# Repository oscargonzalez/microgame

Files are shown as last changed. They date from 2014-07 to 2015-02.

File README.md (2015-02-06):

MicroGame - Custom Arduino Compatible Gamming Platform
======================================================

MicroGame

The MicroGame is an experiment of making a custom portable platform for gamming compatible with Arduino. It's based on a small monochrome 128x64 pixels OLED from Adafruit and a ATmega32U40 8-bits microcontroller running at 8MHz.
All hardware design and game source code is writed from scratch and you can find all the file sin this repository if you want to build your own. You can modify, share and make improvements as you like but do not forget to shoot me and email and show me your work!

First blog post:
http://blog.bricogeek.com/noticias/electronica/microgame-consola-de-juego-casera-basada-en-arduino/

Final proyect post:
http://blog.bricogeek.com/noticias/arduino/microgame-consola-de-juego-compatible-con-arduino-proyecto-final/

Oscar Gonzalez August 2014 - January 2015
www.bricogeek.com

Repository Contents
-------------------
* **/USB driver** - USB driver (tested on Win 7 64-bits). Identifies as Sparkfun Pro Micro 3.3V @ 8MHz
* **/datasheet** - Various datasheets for reference
* **/eagle files** - Eagle design files of the board (schematic and PCB)
* **/src** - Source files for the game for at least Arduino IDE 1.0

License Information
-------------------
The hardware is released under [Creative Commons Share-alike 3.0](http://creativecommons.org/licenses/by-sa/3.0/).  
All other code is open source so please feel free to do anything you want with it; you buy me a beer if you use this and we meet someday ([Beerware license](http://en.wikipedia.org/wiki/Beerware)).

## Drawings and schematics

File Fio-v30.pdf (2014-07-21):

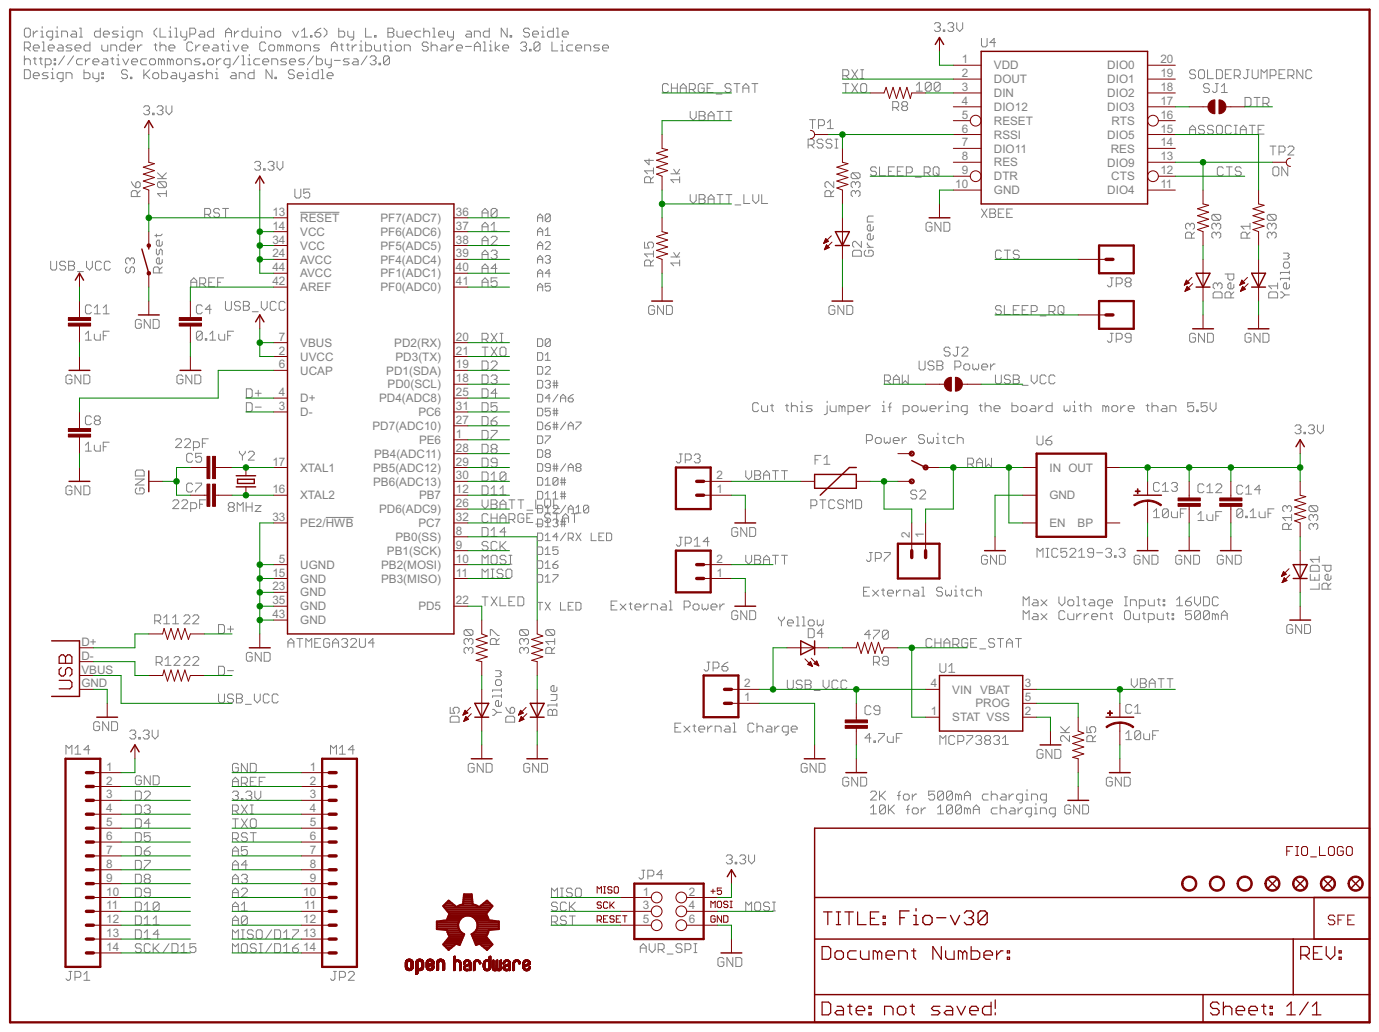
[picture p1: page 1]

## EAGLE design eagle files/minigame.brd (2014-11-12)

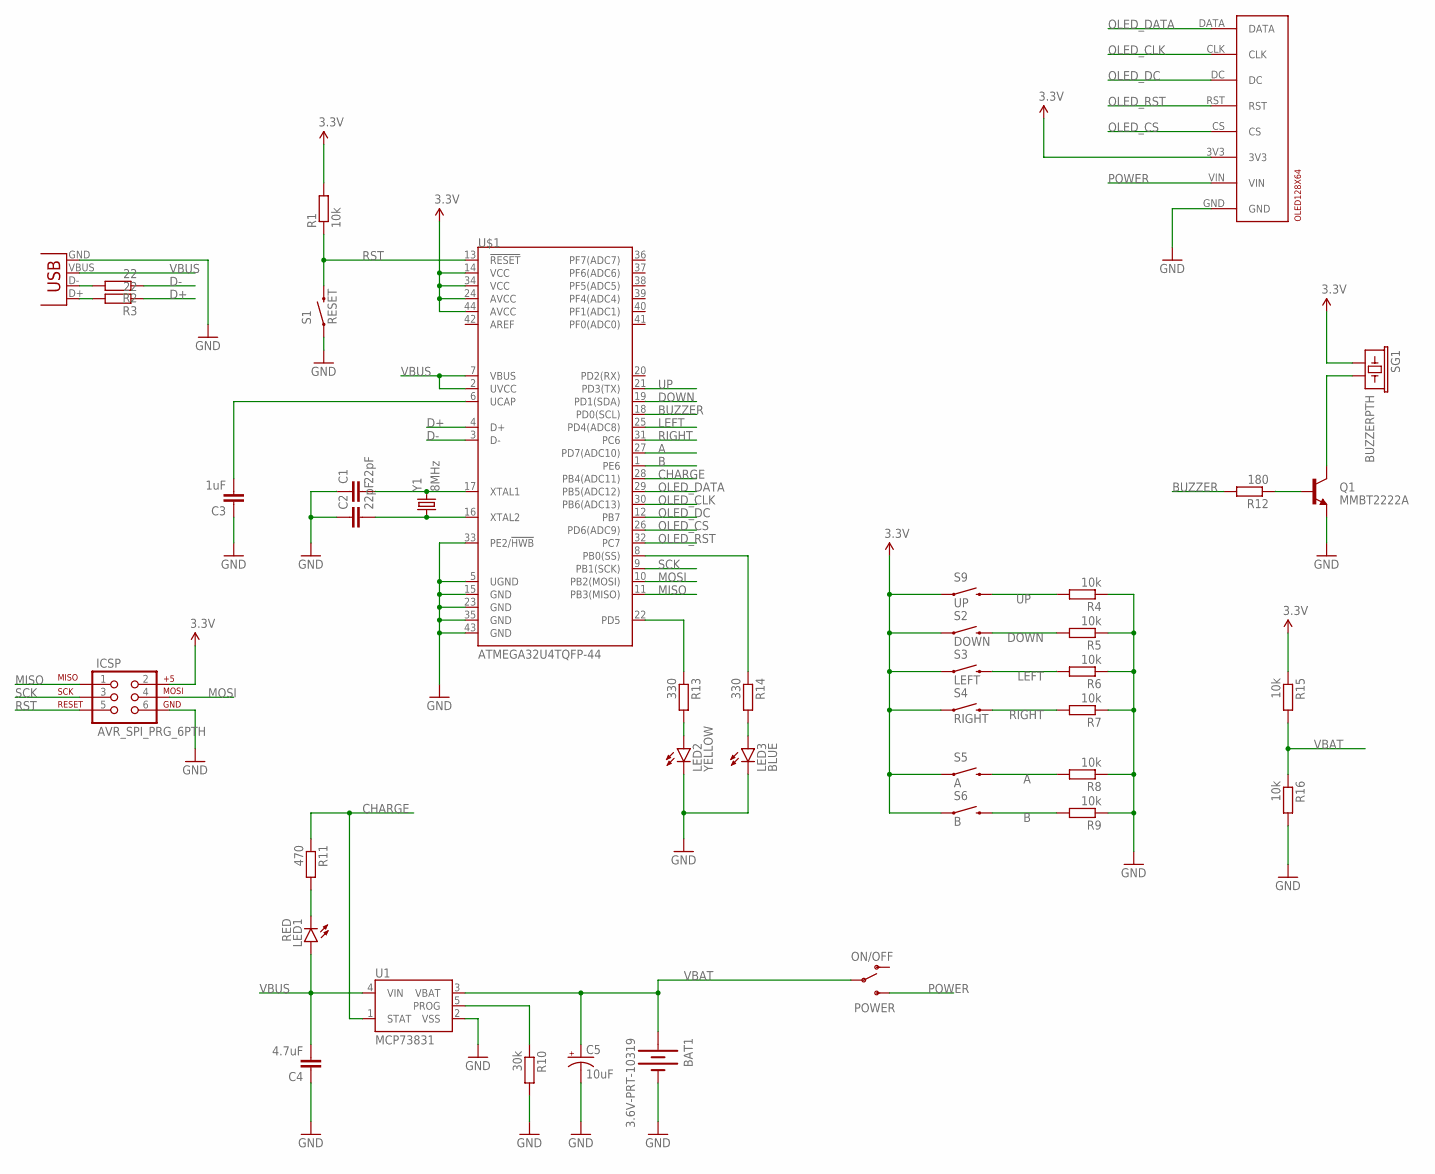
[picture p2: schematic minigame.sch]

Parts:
BAT1: 3.6V-PRT-10319; BATTCON_245MM_PTH
C1, C2: 22pF; 1206
C3: 1uF; 1206
C4: 4.7uF; 1206
C5: 10uF; PANASONIC_D
ICSP: AVR_SPI_PRG_6PTH; 2X3
JP1: USB-SMD-NS; USB-MINIB-NOSTOP
LED1: RED; LED-0603
LED2: YELLOW; LED-0603
LED3: BLUE; LED-0603
OLED128X64: OLED128X64-ADAFRUIT938; 938
POWER: ON/OFF; AYZ0202
Q1: MMBT2222A; SOT23-3
R1, R4, R5, R6, R7, R8, R9, R15, R16: 10k; M0805
R2, R3: 22; M0805
R10: 30k; M0805
R11: 470; M0805
R12: 180; M0805
R13, R14: 330; M0805
S1: RESET; TACTILE-SWITCH-SMD
S2: DOWN; TACTILE_SWITCH_TALL
S3: LEFT; TACTILE_SWITCH_TALL
S4: RIGHT; TACTILE_SWITCH_TALL
S5: A; TACTILE_SWITCH_TALL
S6: B; TACTILE_SWITCH_TALL
S9: UP; TACTILE_SWITCH_TALL
SG1: BUZZERPTH; BUZZER-12MM
U1: MCP73831; SOT23-5
U$1: ATMEGA32U4TQFP-44; TQFP44
Y1: 8MHz; HC49US

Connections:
3.3V: ICSP.2, OLED128X64.3V3, R1.2, R15.1, S2.A2 (1), S3.A2 (1), S4.A2 (1), S5.A2 (1), S6.A2 (1), S9.A2 (1), SG1.+ (1), U$1.14 (VCC), U$1.24 (AVCC), U$1.34 (VCC), U$1.44 (AVCC)
A: R8.2, S5.B2 (2), U$1.27 (PD7(ADC10))
B: R9.2, S6.B2 (2), U$1.1 (PE6)
BUZZER: R12.2, U$1.18 (PD0(SCL))
CHARGE: R11.1, U1.1 (STAT), U$1.28 (PB4(ADC11))
D+: R3.1, U$1.4 (D+)
D-: R2.1, U$1.3 (D-)
DOWN: R5.2, S2.B2 (2), U$1.19 (PD1(SDA))
GND: BAT1.2 (-), C1.1, C2.1, C3.1, C4.1, C5.-, ICSP.6, JP1.GND, LED2.C, LED3.C, OLED128X64.GND, Q1.2 (E), R4.1, R5.1, R6.1, R7.1, R8.1, R9.1, R10.2, R16.2, S1.1, U1.2 (VSS), U$1.5 (UGND), U$1.15 (GND), U$1.23 (GND), U$1.33 (PE2/!HWB), U$1.35 (GND), U$1.43 (GND)
LEFT: R6.2, S3.B2 (2), U$1.25 (PD4(ADC8))
MISO: ICSP.1, U$1.11 (PB3(MISO))
MOSI: ICSP.4, U$1.10 (PB2(MOSI))
unnamed: C1.2, U$1.17 (XTAL1), Y1.2
unnamed: C2.2, U$1.16 (XTAL2), Y1.1
unnamed: Q1.3 (C), SG1.- (2)
unnamed: JP1.D-, R2.2
unnamed: JP1.D+, R3.2
unnamed: C3.2, U$1.6 (UCAP)
unnamed: R10.1, U1.5 (PROG)
unnamed: LED1.C, R11.2
unnamed: Q1.1 (B), R12.1
unnamed: LED2.A, R13.2
unnamed: LED3.A, R14.2
unnamed: R13.1, U$1.22 (PD5)
unnamed: R14.1, U$1.8 (PB0(SS))
OLED_CLK: OLED128X64.CLK, U$1.30 (PB6(ADC13))
OLED_CS: OLED128X64.CS, U$1.26 (PD6(ADC9))
OLED_DATA: OLED128X64.DATA, U$1.29 (PB5(ADC12))
OLED_DC: OLED128X64.DC, U$1.12 (PB7)
OLED_RST: OLED128X64.RST, U$1.32 (PC7)
POWER: OLED128X64.VIN, POWER.3 (S)
RIGHT: R7.2, S4.B2 (2), U$1.31 (PC6)
RST: ICSP.5, R1.1, S1.3 (2), U$1.13 (!RESET)
SCK: ICSP.3, U$1.9 (PB1(SCK))
UP: R4.2, S9.B2 (2), U$1.21 (PD3(TX))
VBAT: BAT1.3 (+), C5.+, POWER.2, R15.2, R16.1, U1.3 (VBAT)
VBUS: C4.2, JP1.VBUS, LED1.A, U1.4 (VIN), U$1.2 (UVCC), U$1.7 (VBUS)

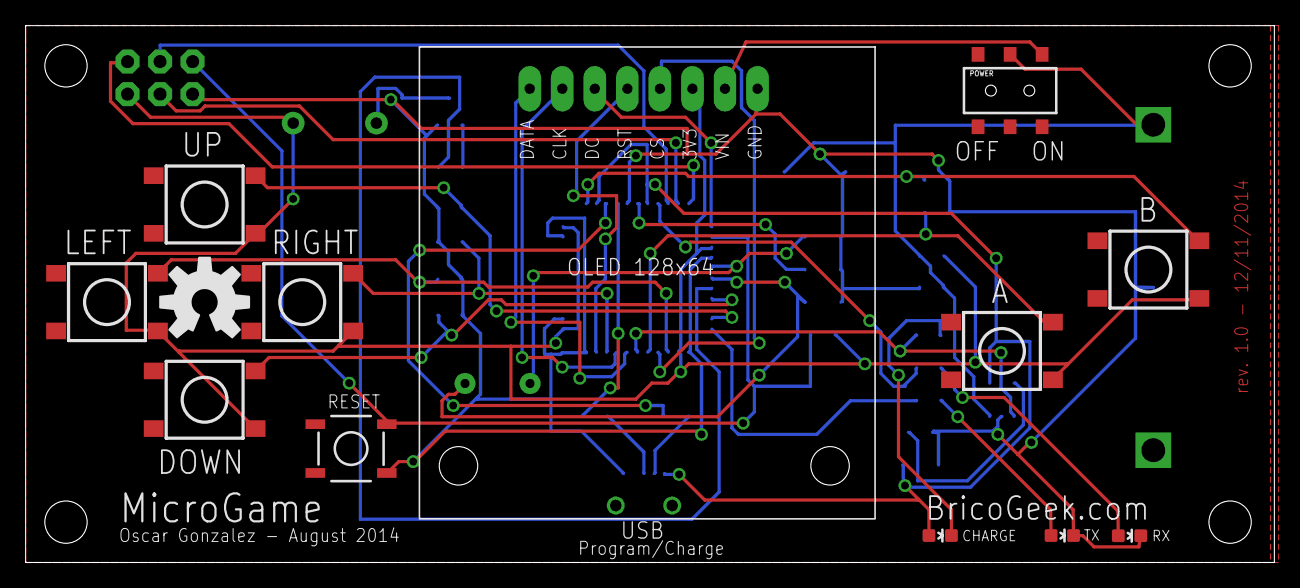
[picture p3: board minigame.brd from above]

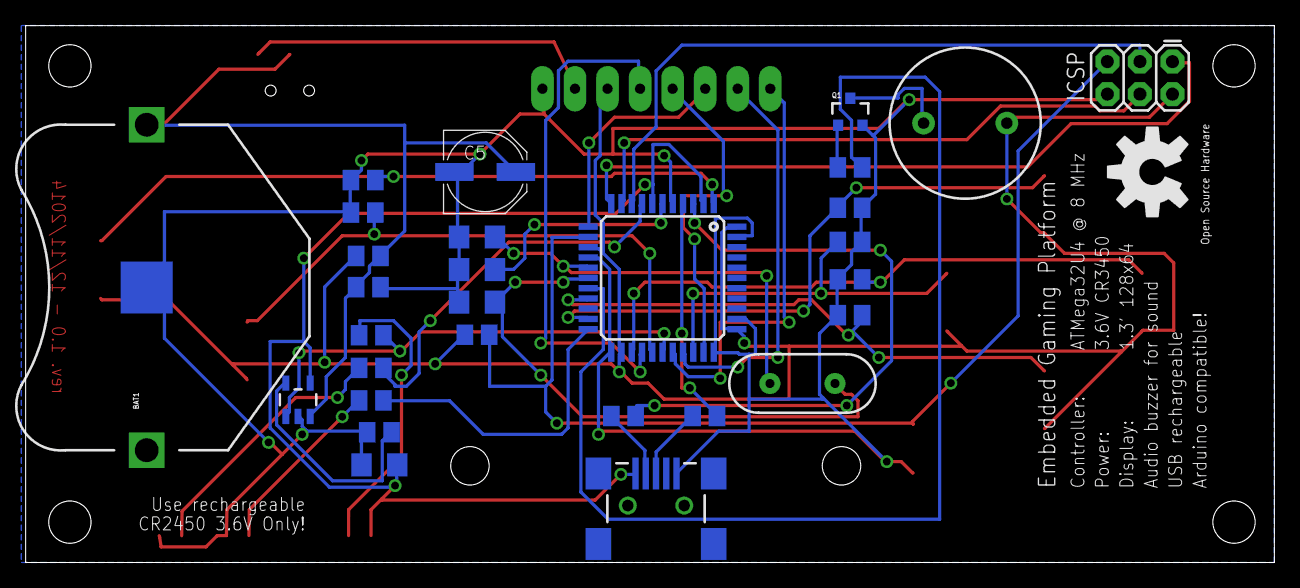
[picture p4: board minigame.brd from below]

Board: 2 copper layers, 97.5 x 41.9 mm, 47 parts (30 on the bottom side), 37 nets.

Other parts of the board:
U$2, U$4, U$5, U$6: STAND-OFF
U$3, U$7: OSHW-LOGO-L

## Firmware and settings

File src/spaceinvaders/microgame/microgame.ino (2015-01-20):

/**************************************************************************************************************

  MicroGame v1.0
  Hardware and Sofware by Oscar Gonzalez
  http:/www.bricogeek.com
  August 2014 - January 2015
  
  Project sources and schematics:
  https://github.com/oscargonzalez/microgame
  
  The hardware is released under Creative Commons Share-alike 3.0
  http://creativecommons.org/licenses/by-sa/3.0/
  
  All other code is open source so please feel free to do anything you want with it; you buy me a beer if you use this and we meet someday (Beerware license)
  http://en.wikipedia.org/wiki/Beerware

***************************************************************************************************************/
#include <SPI.h>
#include <Wire.h>
#include <Adafruit_GFX.h>
#include <Adafruit_SSD1306.h>
#include <EEPROM.h>

// Uncomment this block to use hardware SPI (MUCH faster but not supported in hardware yet, sorry!)
/*
#define OLED_DC     6
#define OLED_CS     7
#define OLED_RESET  8
Adafruit_SSD1306 display(OLED_DC, OLED_RESET, OLED_CS);
*/

// Software SPI (SLOWER!)
#define OLED_MOSI   9
#define OLED_CLK   10
#define OLED_DC    11
#define OLED_CS    12
#define OLED_RESET 13
Adafruit_SSD1306 display(OLED_MOSI, OLED_CLK, OLED_DC, OLED_RESET, OLED_CS);

//Define buttons
#define BUTTON_UP     1
#define BUTTON_DOWN   2
#define BUTTON_LEFT   4
#define BUTTON_RIGHT  5
#define BUTTON_A      6
#define BUTTON_B      7

#define MAX_STARS          10 // Starfield config. The more, the poor...
#define SCOREBOARD_HEIGHT  8
#define MAX_FIRES          3 // Max player fires at the same time
#define BATTESHIP_WIDTH    10
#define BATTESHIP_HEIGHT   7
#define BATTESHIP_FIRE_WIDTH    3  //Width of the shot
#define BATTESHIP_FIRE_SPEED    3 
#define BATTESHIP_FIRE_DELAY    90 //delay between shots in ms

// Define enemy
#define ENEMY_WIDTH       5
#define ENEMY_HEIGHT      5
#define ENEMY_MAX_FIRES   3
#define ENEMY_FIRES_WIDTH 3
#define ENEMY_FIRES_SPEED 3

#define ENEMY_TYPE_1    0
#define ENEMY_TYPE_2    1
#define ENEMY_TYPE_3    2
#define ENEMY_TYPE_4    3
#define ENEMY_TYPE_5    4

#define MAX_ENEMIES     6 // More enemies = more fun and less RAM...
int max_enemies  = 3; // This will change in realtime (more enemies, more dificult!)
int total_enemies  = 0; // This will change in realtime (more enemies, more dificult!)
int current_score = 0; // Current player score
int max_lives     = 3; // Total lives to play

// Splash logo 128x64
const unsigned char PROGMEM splash_logo [] = { 0, 0, 0, 0, 0, 0, 0, 0, 0, 0, 0, 0, 0, 0, 0, 0, 0, 0, 0, 0, 0, 0, 0, 0, 0, 0, 0, 0, 0, 0, 0, 0, 0, 0, 0, 0, 0, 0, 0, 0, 0, 0, 0, 0, 0, 0, 0, 0, 0, 0, 0, 0, 0, 0, 0, 0, 0, 0, 0, 0, 0, 0, 0, 0, 0, 0, 0, 0, 0, 0, 0, 0, 0, 0, 0, 0, 0, 0, 0, 0, 0, 0, 0, 0, 0, 0, 0, 0, 0, 0, 0, 0, 0, 0, 0, 0, 0, 0, 0, 0, 0, 0, 0, 0, 0, 0, 0, 0, 0, 0, 0, 0, 0, 0, 0, 0, 0, 0, 0, 0, 0, 0, 0, 0, 0, 0, 0, 0, 0, 0, 0, 0, 0, 0, 0, 0, 0, 0, 0, 0, 0, 0, 0, 0, 0, 0, 0, 0, 0, 0, 0, 0, 0, 0, 0, 0, 0, 0, 0, 0, 0, 0, 0, 0, 0, 0, 0, 0, 0, 0, 0, 0, 0, 0, 0, 0, 0, 0, 0, 0, 0, 0, 0, 0, 0, 0, 0, 0, 0, 0, 0, 0, 0, 0, 192, 48, 192, 0, 0, 0, 0, 15, 224, 0, 0, 0, 0, 0, 0, 0, 224, 112, 0, 0, 0, 0, 0, 56, 0, 0, 0, 0, 0, 0, 0, 0, 224, 240, 0, 0, 0, 0, 0, 96, 0, 0, 0, 0, 0, 0, 0, 1, 225, 224, 0, 0, 0, 0, 0, 192, 0, 0, 0, 0, 0, 0, 0, 1, 243, 96, 0, 0, 0, 0, 0, 192, 0, 0, 0, 0, 0, 0, 0, 1, 182, 97, 131, 240, 254, 7, 192, 192, 3, 248, 31, 248, 15, 128, 0, 3, 60, 195, 6, 1, 140, 28, 193, 135, 128, 28, 49, 156, 24, 192, 0, 3, 60, 195, 12, 1, 128, 48, 97, 129, 128, 12, 49, 140, 48, 192, 0, 3, 56, 195, 12, 1, 128, 48, 97, 129, 128, 12, 49, 140, 48, 192, 0, 6, 1, 134, 24, 3, 0, 96, 195, 3, 0, 24, 99, 24, 96, 192, 0, 6, 1, 134, 24, 3, 0, 96, 195, 3, 7, 248, 99, 24, 127, 192, 0, 6, 1, 134, 24, 3, 0, 96, 195, 3, 12, 24, 99, 24, 96, 0, 0, 12, 3, 12, 48, 6, 0, 193, 134, 6, 24, 48, 198, 48, 192, 0, 0, 12, 3, 12, 48, 6, 0, 193, 135, 6, 24, 48, 198, 48, 192, 0, 0, 12, 3, 12, 56, 6, 0, 231, 3, 6, 24, 48, 198, 48, 192, 0, 0, 24, 6, 24, 31, 12, 0, 124, 1, 252, 15, 225, 140, 96, 127, 0, 0, 0, 0, 0, 0, 0, 0, 0, 0, 0, 0, 0, 0, 0, 0, 0, 0, 0, 0, 0, 0, 0, 0, 0, 0, 0, 0, 0, 0, 0, 0, 0, 0, 0, 0, 0, 0, 0, 0, 0, 0, 0, 0, 0, 0, 0, 0, 0, 0, 0, 0, 0, 0, 0, 0, 0, 0, 0, 0, 0, 0, 0, 0, 0, 0, 0, 0, 0, 0, 0, 0, 0, 0, 0, 0, 0, 0, 0, 0, 0, 0, 0, 0, 0, 0, 0, 0, 0, 0, 0, 0, 0, 0, 0, 0, 0, 0, 0, 0, 0, 0, 0, 0, 0, 0, 0, 0, 0, 0, 0, 0, 0, 0, 0, 0, 0, 0, 0, 0, 0, 0, 0, 0, 0, 0, 0, 0, 0, 0, 0, 0, 0, 0, 0, 0, 0, 0, 0, 0, 0, 0, 0, 0, 0, 0, 0, 0, 0, 0, 0, 0, 0, 0, 0, 0, 0, 0, 0, 0, 0, 0, 0, 0, 0, 0, 0, 0, 0, 0, 0, 0, 0, 0, 0, 0, 0, 0, 0, 0, 28, 0, 0, 0, 14, 0, 0, 0, 32, 0, 0, 0, 0, 0, 0, 0, 34, 0, 0, 0, 17, 0, 0, 0, 32, 0, 0, 0, 0, 0, 0, 0, 65, 56, 227, 148, 32, 156, 243, 231, 39, 62, 0, 0, 0, 0, 0, 0, 65, 69, 20, 88, 32, 34, 136, 72, 168, 132, 0, 0, 0, 0, 0, 0, 65, 49, 3, 208, 35, 162, 136, 135, 175, 136, 0, 0, 0, 0, 0, 0, 65, 9, 4, 80, 32, 162, 136, 136, 168, 8, 0, 0, 0, 0, 0, 0, 34, 69, 20, 208, 17, 34, 137, 9, 168, 144, 0, 0, 0, 0, 0, 0, 28, 56, 227, 80, 14, 28, 139, 230, 167, 62, 0, 0, 0, 0, 0, 0, 0, 0, 0, 0, 0, 0, 0, 0, 0, 0, 0, 0, 0, 0, 0, 0, 0, 0, 0, 0, 0, 0, 0, 0, 0, 0, 0, 0, 0, 0, 0, 0, 0, 0, 0, 0, 0, 0, 0, 0, 0, 0, 0, 0, 0, 0, 0, 0, 0, 0, 0, 0, 0, 0, 0, 0, 0, 0, 0, 0, 0, 0, 0, 0, 0, 0, 0, 0, 0, 0, 0, 0, 0, 0, 0, 0, 0, 0, 0, 0, 0, 0, 0, 0, 0, 0, 0, 0, 0, 0, 0, 0, 0, 0, 0, 0, 0, 4, 0, 0, 7, 28, 32, 64, 0, 0, 0, 0, 0, 0, 0, 0, 0, 10, 0, 0, 8, 162, 96, 192, 0, 0, 0, 0, 0, 0, 0, 0, 0, 10, 34, 104, 0, 162, 161, 64, 0, 0, 0, 0, 0, 0, 0, 0, 0, 10, 34, 152, 0, 162, 33, 64, 0, 0, 0, 0, 0, 0, 0, 0, 0, 17, 34, 136, 1, 34, 34, 64, 0, 0, 0, 0, 0, 0, 0, 0, 0, 31, 34, 136, 2, 34, 35, 224, 0, 0, 0, 0, 0, 0, 0, 0, 0, 32, 166, 152, 4, 34, 32, 64, 0, 0, 0, 0, 0, 0, 0, 0, 0, 32, 154, 105, 15, 156, 32, 64, 0, 0, 0, 0, 0, 0, 0, 0, 0, 0, 0, 8, 0, 0, 0, 0, 0, 0, 0, 0, 0, 0, 0, 0, 0, 0, 0, 240, 0, 0, 0, 0, 0, 0, 0, 0, 0, 0, 0, 0, 0, 0, 0, 0, 0, 0, 0, 0, 0, 0, 0, 0, 0 };    

// Numbers font (4x5)
const unsigned char PROGMEM number_0 [] = { 96, 144, 144, 144, 96 }; // 0
const unsigned char PROGMEM number_1 [] = { 32, 96, 32, 32, 32 }; // 1    
const unsigned char PROGMEM number_2 [] = { 96, 144, 32, 64, 240 }; // 2    
const unsigned char PROGMEM number_3 [] = { 96, 16, 48, 16, 96 }; // 3    
const unsigned char PROGMEM number_4 [] = { 128, 160, 224, 32, 32 }; // 4    
const unsigned char PROGMEM number_5 [] = { 240, 128, 240, 16, 240 }; // 5    
const unsigned char PROGMEM number_6 [] = { 240, 128, 240, 144, 240  }; // 6   
const unsigned char PROGMEM number_7 [] = { 240, 16, 96, 64, 64 }; // 7    
const unsigned char PROGMEM number_8 [] = { 240, 144, 240, 144, 240  }; // 8    
const unsigned char PROGMEM number_9 [] = { 240, 144, 240, 16, 112 }; // 9    
  
// Ship: 10x7
const unsigned char PROGMEM ship [] = {  240, 0, 249, 0, 48, 128, 127, 192, 48, 128, 249, 0, 240, 0 };    

// enemies: 5x5
const unsigned char PROGMEM enemy1 [] = { 32, 168, 248, 112, 136 }; 
const unsigned char PROGMEM enemy2 [] = { 24, 48, 248, 48, 24 };    
const unsigned char PROGMEM enemy3 [] = { 216, 112, 80, 112, 168 };    
const unsigned char PROGMEM enemy4 [] = { 136, 168, 248, 112, 216 };    
const unsigned char PROGMEM enemy5 [] = { 80, 248, 248, 112, 168 };    

//Enemy explosion
const unsigned char PROGMEM enemy_explode1 [] = { 0, 0, 32, 0, 0 };    
const unsigned char PROGMEM enemy_explode2 [] = { 0, 80, 32, 80, 0 };    
const unsigned char PROGMEM enemy_explode3 [] = { 136, 80, 32, 80, 136 };    
const unsigned char PROGMEM enemy_explode4 [] = { 136, 80, 0, 80, 136 };    
const unsigned char PROGMEM enemy_explode5 [] = {  136, 0, 0, 0, 136 };    

//Define a 2D point
struct tPos {
   int x;
   int y; 
};

// define a button
struct control_def {
    boolean currentState;
    boolean lastState;
    boolean debouncedState;
    int debounceInterval;
    unsigned long timeOfLastButtonEvent;  
};

/*======================================================================
  BattleShip class definition
  ======================================================================*/
class Battleship
{
  public:
    Battleship();
    void update();
    void moveRight();
    void moveLeft();
    void moveUp();
    void moveDown();
    void Fire();
    void setPosition(int x, int y);
    tPos getTpos(int x, int y);
    boolean isInsideRect(tPos point, tPos rectpos, int width, int height);
    
    // Internals (also public...)
    int _x;
    int _y;   
    int _velocity;   
    int fire_count;
    tPos fires[MAX_FIRES];
    unsigned long last_fire;
};

Battleship::Battleship()
{
    int i;
    
   _x = 0;
   _y = 32 - (BATTESHIP_HEIGHT/2); 
   _velocity=2;
   fire_count=0;
   last_fire=0;
   for (i=0;i<MAX_FIRES;i++) { fires[i].x=0; }
}

void Battleship::moveRight()   { if (_x < (128-BATTESHIP_WIDTH)-2)  { _x +=2; } }
void Battleship::moveLeft()    { if (_x > 0)                        { _x -=2; } }
void Battleship::moveUp()      { if (_y > 8)                        { _y -=2; } }
void Battleship::moveDown()    { if (_y < (64-BATTESHIP_HEIGHT))    { _y +=2; } }
void Battleship::setPosition(int x, int y) { _x=x; _y=y; }
void Battleship::Fire()
{  

  if (fire_count < MAX_FIRES)
  {
    if (millis()-last_fire > BATTESHIP_FIRE_DELAY)
    {

      tone(3, 100, 120);

     for (int i=0 ; i<MAX_FIRES; i++)
     {
        Serial.print(fires[i].x); Serial.print("-");
       if (fires[i].x == 0)
       {
         fires[i].x = _x + BATTESHIP_WIDTH;
         fires[i].y = _y + (BATTESHIP_HEIGHT/2); // Divide in realtime is bad ;)
         fire_count++;
         last_fire=millis();
         break;
       }
     }
    }
  }
}

void Battleship::update()
{
  
  int i,j;
  
  // Update position
  display.drawBitmap(_x, _y,  ship, BATTESHIP_WIDTH, BATTESHIP_HEIGHT, 1);

  // Update fire
  for (i=0 ; i<MAX_FIRES ; i++)
  {
    //BATTESHIP_FIRE_WIDTH     
    if (fires[i].x > 0)
    { 
      fires[i].x += BATTESHIP_FIRE_SPEED;
      for (j=0 ; j<BATTESHIP_FIRE_WIDTH ; j++) { display.drawPixel(fires[i].x-j, fires[i].y, WHITE); } // Draw 3 pixels back for the full shot      
      
      //Shot is dead
      if (fires[i].x > (128-BATTESHIP_FIRE_WIDTH))
      {        
        fires[i].x=0; 
        fire_count--;
      }
      
    }    
  }
}

// Helper return tPos from coordinates
tPos Battleship::getTpos(int x, int y)
{
  tPos p;
  p.x = x; p.y= y;
  return p;
}

// Helper:
// Return TRUE if the point is inside a rectagle by given by width and height
boolean Battleship::isInsideRect(tPos point, tPos rectpos, int width, int height)
{
  if ( (point.x >= rectpos.x) && 
       (point.y >= rectpos.y) &&
       (point.x <  (rectpos.x+width)) &&
       (point.y <  (rectpos.y+height)) )
       {
        return true; 
       }
       else { return false; }
}

/*======================================================================
  Enemy class definition
  ======================================================================*/
class Enemy {
  public:
    Enemy();
    void update();
    tPos getPosition();
    void create();
    void destroy();
    
    // Internals (also public...)
    boolean islive; // Enemy is alive!
    boolean isdead; // Enemy died!
    int _type;        // Type of enemy
    int _deadanim_num;
    tPos position;
    int _x;
    int _y;    
    unsigned long last_millis;  
    unsigned long fire_delay_ms;  
    const unsigned char *sprite;
    int reward_points;
};

Enemy::Enemy()
{
    islive=false;
    isdead=false;
    _type=0;
    _x=0;
    _y=0;

    _deadanim_num=-1;

    position.x=0;
    position.y=0;
    fire_delay_ms=0;
    last_millis=0;    

    reward_points=0;
}

void Enemy::create()
{
    if (total_enemies < MAX_ENEMIES)
    {
    
      islive=true;
      isdead=false;
      _type= random(1, 5);    

      switch (_type)
      {
        case 1: reward_points=1; break;
        case 2: reward_points=2; break;
        case 3: reward_points=3; break;
        case 4: reward_points=4; break;
        case 5: reward_points=5; break;
      }

      position.x = 100;
      position.y = random(10, 50);

      _deadanim_num=-1;
      
      last_millis = millis();
      fire_delay_ms = random(200,2500);
      
      total_enemies++;
    }
}


void Enemy::update()
{
  
  if ( (!islive) ) {return;}
    
  float animx;
  float animy;

  if (_deadanim_num == -1)      
  {
    switch (_type)
    {
       case 1: {
         sprite=enemy1; 
         animx = (0.001*(millis()-last_millis));
         animy = (0.003*(millis()-last_millis));
         _x = (position.x+sin(animx)*20);
         _y = position.y+cos(animx)*16;       
       } break;
       case 2: {
         sprite=enemy2; 
         animx = (0.002*(millis()-last_millis));
         animy = (0.009*(millis()-last_millis));
         _x = position.x+sin(animx)*20;
         _y = position.y+cos(animx)*16;              
       } break;
       case 3: { 
         sprite=enemy3; 
         animx = (0.0005*(millis()-last_millis));
         animy = (0.009*(millis()-last_millis));
         _x = position.x+cos(animx)*20;
         _y = position.y+sin(animx)*16;              
       } break;
       case 4: { 
         sprite=enemy4; 
         animx = (0.003*(millis()-last_millis));
         animy = (0.005*(millis()-last_millis));
         _x = position.x+sin(animx)*20;
         _y = position.y+cos(animx)*16;              
       } break;
       case 5: {
         sprite=enemy5; 
         animx = (0.008*(millis()-last_millis));
         animy = (0.0007*(millis()-last_millis));
         _x = position.x+cos(animx)*20;
         _y = position.y+sin(animx)*16;              
       } break;
    }

    display.drawBitmap(_x, _y,  sprite, 5, 5, 1); // Draw
  }
  else
  {

      // Enemy dead animation
      if (_deadanim_num == 0) { display.drawBitmap(_x, _y,  enemy_explode1, 5, 5, 1); }
      if (_deadanim_num == 1) { display.drawBitmap(_x, _y,  enemy_explode2, 5, 5, 1); }
      if (_deadanim_num == 2) { display.drawBitmap(_x, _y,  enemy_explode3, 5, 5, 1); }
      if (_deadanim_num == 3) { display.drawBitmap(_x, _y,  enemy_explode4, 5, 5, 1); }
      if (_deadanim_num == 4) { display.drawBitmap(_x, _y,  enemy_explode5, 5, 5, 1); }

      if ( (millis()-last_millis) > 90) { 
        _deadanim_num++;
        last_millis=millis();
        if (_deadanim_num > 4) {
           // End of dead animation
           _deadanim_num=0;
           islive=false; 
           total_enemies--;                     
        }
      }      
  }
  
}

void Enemy::destroy()
{   
   _deadanim_num = 0;
   last_millis=millis();
}

/*======================================================================
  Collider class
  ======================================================================*/
class Collider 
{
  public:
    void check(Battleship m_nave, Enemy *m_enemy);
};

//Check for collisions
void Collider::check(Battleship m_nave, Enemy *m_enemy)
{
  
   //Get all our battleship shots
   for (int i=0 ; i<MAX_FIRES; i++)
   {
     if (m_nave.fires[i].x > 0)
     {
       
       // Check all enemies position for collision
       for (int j=0;j<MAX_ENEMIES ; j++)
       {
         //fires[i].x
         //fires[i].y     
         if (m_enemy[j].islive)
         {
           // Check if we hit some alien
           if (m_nave.isInsideRect(m_nave.getTpos(m_nave.fires[i].x, m_nave.fires[i].y), 
                            m_nave.getTpos(m_enemy[j]._x, m_enemy[j]._y), 
                            ENEMY_WIDTH, ENEMY_HEIGHT))  
                          {                            

                              m_nave.fires[i].x = 0;   // Stop fire                         
                              m_nave.fires[i].y = 0;   // Stop fire                                                       

                            if (m_enemy[j]._deadanim_num == -1) // If not allready in dead mode
                            {
                              // Alien collided!                            

                              current_score += m_enemy[j].reward_points; // Increase current points based on enemy value

                              m_enemy[j].destroy(); // Destroy enemy
                              m_nave.fires[i].x=0;
                              tone(3, 600, 80);
                            }
                          }  
         }
       }
     }
   }

   // Check if some alien hit the battelship
   for (int j=0;j<MAX_ENEMIES ; j++)
   {
     //fires[i].x
     //fires[i].y     
     if (m_enemy[j].islive)
     {   
         if (m_nave.isInsideRect(m_nave.getTpos(m_enemy[j]._x, m_enemy[j]._y), 
                                 m_nave.getTpos(m_nave._x, m_nave._y), 
                                 ENEMY_WIDTH, ENEMY_HEIGHT))
                                 {
                                    max_lives--;
                                    m_nave.setPosition(0, 32);
                                    m_nave.update();  
                                    tone(3, 1000, 1000);
                                    delay(500);
                                    break;                                    
                                 }          
     }
   }

}

/*======================================================================
  Starfield class definition
  ======================================================================*/
class Starfield 
{
  public:
    Starfield();
    void update();
    
 private:
   tPos stars[MAX_STARS];
};

Starfield::Starfield()
{  
  for (int i=0; i<MAX_STARS ; i++)
  {
      stars[i].x = random(0, 127);
      stars[i].y = random(SCOREBOARD_HEIGHT, 63);      
  }
}

void Starfield::update()
{

    for (int i=0 ; i<MAX_STARS ; i++)
    {
      display.drawPixel(stars[i].x, stars[i].y, BLACK);
      stars[i].x-=1;    
      display.drawPixel(stars[i].x, stars[i].y, WHITE);
      
      if (stars[i].x <= 1) { 
        display.drawPixel(stars[i].x, stars[i].y, BLACK);
        stars[i].x = 127;      
        stars[i].y = random(SCOREBOARD_HEIGHT, 63);      
      }
    }
     
}

/*======================================================================
  Controls class definition
  ======================================================================*/
class Controls {
  public:
    Controls();
    boolean getButton(int button_pin);
    
    control_def _ctrl[6];
};  

Controls::Controls()
{
    for(int i=0;i<6;i++)
    {
      _ctrl[i].currentState = LOW;//stroage for current measured button state
      _ctrl[i].lastState = LOW;//storage for last measured button state
      _ctrl[i].debouncedState = LOW;//debounced button state      
      _ctrl[i].debounceInterval = 20;//wait 20 ms for button pin to settle
      _ctrl[i].timeOfLastButtonEvent = 0;//store the last time the button state changed        
    }
}

boolean Controls::getButton(int button_pin)
{
  
  //---
  int pin;
  
  if (button_pin == BUTTON_UP) { pin=0; }
  if (button_pin == BUTTON_DOWN) { pin=1; }
  if (button_pin == BUTTON_LEFT) { pin=2; }
  if (button_pin == BUTTON_RIGHT) { pin=3; }
  if (button_pin == BUTTON_A) { pin=4; }
  if (button_pin == BUTTON_B) { pin=5; }
  
  _ctrl[pin].currentState = digitalRead(button_pin);
  unsigned long currentTime = millis();
  
  if (_ctrl[pin].currentState != _ctrl[pin].lastState){
    _ctrl[pin].timeOfLastButtonEvent = currentTime;
  }

  if (currentTime - _ctrl[pin].timeOfLastButtonEvent > _ctrl[pin].debounceInterval){//if enough time has passed
    if (_ctrl[pin].currentState != _ctrl[pin].debouncedState){//if the current state is still different than our last stored debounced state
      _ctrl[pin].debouncedState = _ctrl[pin].currentState;//update the debounced state
      
      //trigger an event
      if (_ctrl[pin].debouncedState == HIGH){
        return true;
      } else {
        return false;
      }
    }
  }

  _ctrl[pin].lastState = _ctrl[pin].currentState;
  
}

/*======================================================================
  Scores class definition
  ======================================================================*/
class Scores {

  public:
    Scores();
    void draw();    
    void gameover();

    // Read/write scores as INTEGER (Thanks to http://forum.arduino.cc/index.php/topic,37470.0.html)
    void saveScore(int p_value);
    unsigned int readScore();

    int high_score;

};

Scores::Scores()
{

  high_score = 0;

  // First check EEPROM. Must have 'M' on address 0 and 'G' on address 1
  // Hi score start at address 2
  if ( (EEPROM.read(0) != 'M') && (EEPROM.read(0) != 'G') )
  {
    // It seems the EEPROM is empty or not initialised
    EEPROM.write(0, 'M');
    EEPROM.write(1, 'G');
    saveScore(0);        
  }
  else
  {
    high_score = readScore();
  }

  Serial.print("High score is: ");
  Serial.println(high_score);

}
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
void loop() {
  
  int x=0;
  
  display.clearDisplay();
  
  //nave.setPosition(0, 32+sin(inc)*20);
  if (controls.getButton(BUTTON_UP)) { nave.moveUp(); }
  if (controls.getButton(BUTTON_DOWN)) { nave.moveDown(); }
  if (controls.getButton(BUTTON_LEFT)) { nave.moveLeft(); }
  if (controls.getButton(BUTTON_RIGHT)) { nave.moveRight(); }    
  if (controls.getButton(BUTTON_A)) { nave.Fire(); }
  
  // Create enemies each second
  if (millis()-last_enemy > 1000)
  {
      if (total_enemies < max_enemies)
      {
       enemies[total_enemies].create();        
       last_enemy=millis();
      }
  }  

  inc+=0.06;
           
  stars.update();
  nave.update();  
  collisions.check(nave, enemies);

  for(x=0;x<MAX_ENEMIES;x++)
  {
   enemies[x].update();
  }

  score.draw();     
 
     Serial.println(max_lives);
  if (max_lives == -1)
  {
    score.gameover();
  }
      
  // Draw framebuffer
  display.display();    
     
  //FPS counter 
  if (millis()-last_time > 1000)
  {
     last_time=millis();
     Serial.print(fps);
     Serial.println(" FPS");
     fps=0;
  }    
  else
  {
     fps++; 
  }
  
}

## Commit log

2014-07-21 Added regulador and charger circuit
2014-07-22 Vista preliminar de la placa (BRD)
    [minigame.brd, minigame.sch]
2014-07-22 Added OLED wires Added buzzer circuit
    [minigame.brd, minigame.sch]
2014-07-22 Added RX/TX LEDs
    [minigame.brd, minigame.sch]
2014-07-24 Added OLED border in BRD
    [minigame.brd]
2014-07-24 Preliminary components placement
    [minigame.brd, minigame.sch]
2014-07-25 Board placement
    [minigame.brd]
2014-07-25 Added Arduino code and some sprites!
2014-07-26 Starfield fix (too slow!)
    [microgame.ino]
2014-07-27 Updated sprites New enemys!(5 in total) Fixed starfield. Now in panoramic mode (right to left) Some defines for finetuning
    [microgame.ino]
2014-07-28 Collision class and first test
    [microgame.ino]
2014-07-28 Added enemy explosion sprite (5 frames)
2014-07-29 Added holes and dimensions
    [minigame.brd]
2014-07-29 Holes fix
    [minigame.brd]
2014-08-01 Now using hardware SPI(must faster!) with Sparkfun ProMicro 3.3V @8MHz
2014-08-01 Test font function (not working)
    [microgame.ino]
2014-08-07 Added button controls
2014-08-07 fix controls with array
    [microgame.ino]
2014-08-13 Display score Fix battleship first position
    [microgame.ino]
2014-10-05 Ajuste en PCB
    [minigame.brd]
2014-10-16 Ripup board layout
    [minigame.brd, minigame.sch]
2014-10-16 Voltage regulator removed Preliminary Routing test
    [minigame.brd, minigame.sch]
2014-11-12 Added new custom package for OLED display Updated schematic
    [minigame.brd, minigame.sch]
2014-11-12 Board 100% routed!
    [minigame.brd]
2014-11-12 Ground plane in top and bottom
    [minigame.brd]
2014-11-12 Added some stuff to board layout and cleaning
    [minigame.brd]
2015-01-19 Added datasheets Added USB driver (Win 7 32/64bits) Added original Sparkfun Pro Micro reference files and docs Moved Eagle files
    [minigame.brd, minigame.sch]
2015-01-19 Changed directory name for microgame source Fix pin assignment for software SPI (ouch!)
    [microgame.ino]
2015-01-20 Some game fixes and gameover screen.
    [microgame.ino]
2015-01-20 Little fixes in game and updated readme
    [microgame.ino]

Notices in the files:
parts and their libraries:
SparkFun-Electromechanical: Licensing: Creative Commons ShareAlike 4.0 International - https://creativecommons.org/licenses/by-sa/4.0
